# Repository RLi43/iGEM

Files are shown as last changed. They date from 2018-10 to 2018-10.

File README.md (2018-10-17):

# iGEM
iGEM 2018, Team Tsinghua-A, Hardware

http://2018.igem.org/Team:Tsinghua-A/Hardware
## Introduce
In order to achieve portable and simple field allergy detection, we designed and manufactured the hardware testing equipment for this project - a small, inexpensive ($20) system, including a device can measure OD600 and fluorescence intensity, and a small automatic vibration device avoiding the sinking of cells.

The device supports battery or micro USB for power supply. According to the prompts on the display, you can get started quickly; the device will judge your allergies based on the cell concentration and fluorescence intensity after a certain period of reaction.

In addition to the detection applied to this project, this device can also be used in other environments where fast and portable spectrophotometric detection or fluorescence intensity detection is needed.

We refer to the design of Team Aachen, 2014, but our Devices are more automated and miniaturized.
## Purchase links
* Processor - Beetle
  * http://www.dfrobot.com.cn/goods-839.html
* LED
  * https://item.taobao.com/item.htm?id=567709749083&_u=i2o6d15v87f5
* Light sensor - TSL235R
  * https://item.taobao.com/item.htm?id=565636235189&_u=i2o6d15vf405
* Filter 
  * https://item.taobao.com/item.htm?id=17750785336&_u=i2o6d15v0f55
  * https://item.taobao.com/item.htm?id=17750785336&_u=i2o6d15v0f55
* Power Module
  * https://item.taobao.com/item.htm?id=574483932087&_u=i2o6d15v1b27
* Battery
  * https://item.taobao.com/item.htm?id=572016229153&_u=i2o6d15v4163
* botton cell
  * https://detail.tmall.com/item.htm?id=546024499215&_u=i2o6d15vbf31
* botton cell holder
  * https://detail.tmall.com/item.htm?id=41299310430&_u=i2o6d15vac5e
* button
  * https://item.taobao.com/item.htm?id=555064300186&_u=i2o6d15v3976
* cuvette
  * https://item.taobao.com/item.htm?id=45424177939&_u=i2o6d15v07f3
* vibration motor
  * https://detail.tmall.com/item.htm?id=522098372457&_u=i2o6d15v0945

## Trying to make it
Following the reference on wiki, you may confort some problems. Here are some suggestions.
1. Use black material to print 3D parts. At least, paint the inside surface black. Avoiding environment light is imprtant.
2. Take care when you welding or installing parts. They are fragile.
3. Maybe you can delete some unfit design. (e.g. the fragile connection)
## Contact
About hardware : jf-li16@mails.tsinghua.edu.cn

About iGEM team Tsinghua-A 2018 : igem2018_thua@163.com

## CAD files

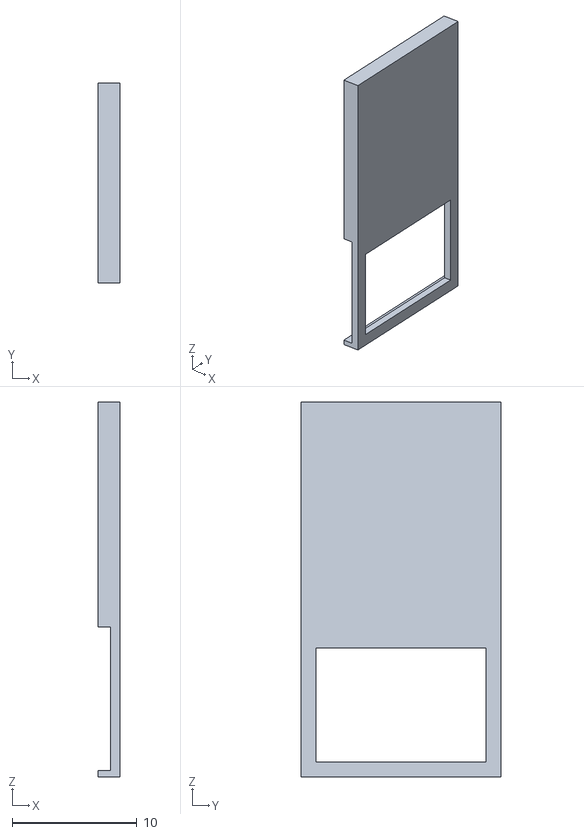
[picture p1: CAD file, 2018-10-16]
滤光片板1_v2_0.stl
1.75 x 16.0 x 30.0

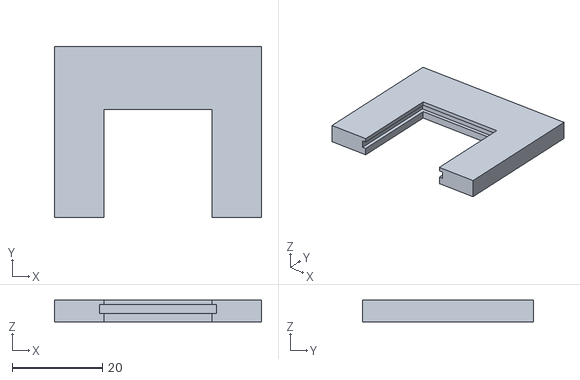
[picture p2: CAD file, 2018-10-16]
遮挡v2_1.stl
46.0 x 38.0 x 4.80

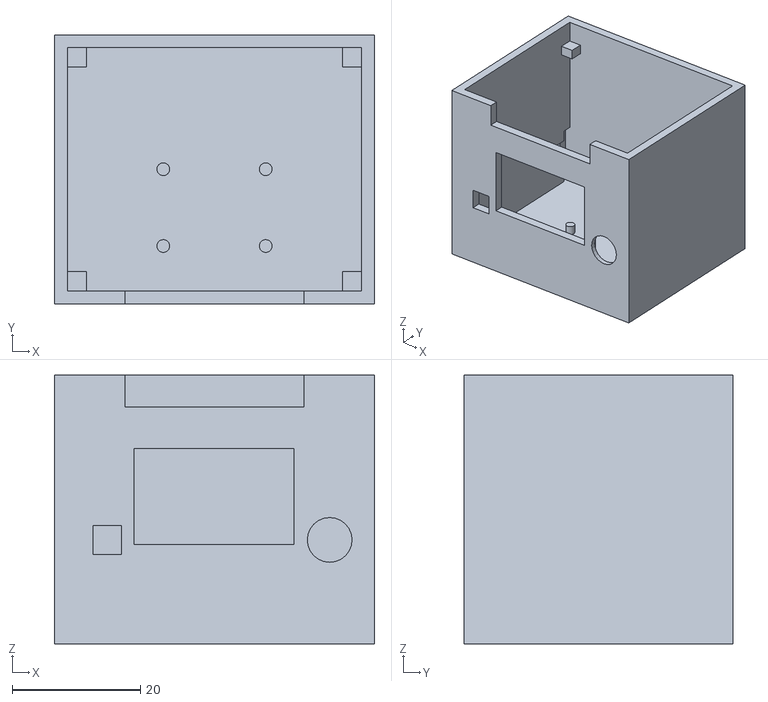
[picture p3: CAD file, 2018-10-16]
盒子外部v2_1.stl
50.0 x 42.1 x 42.0

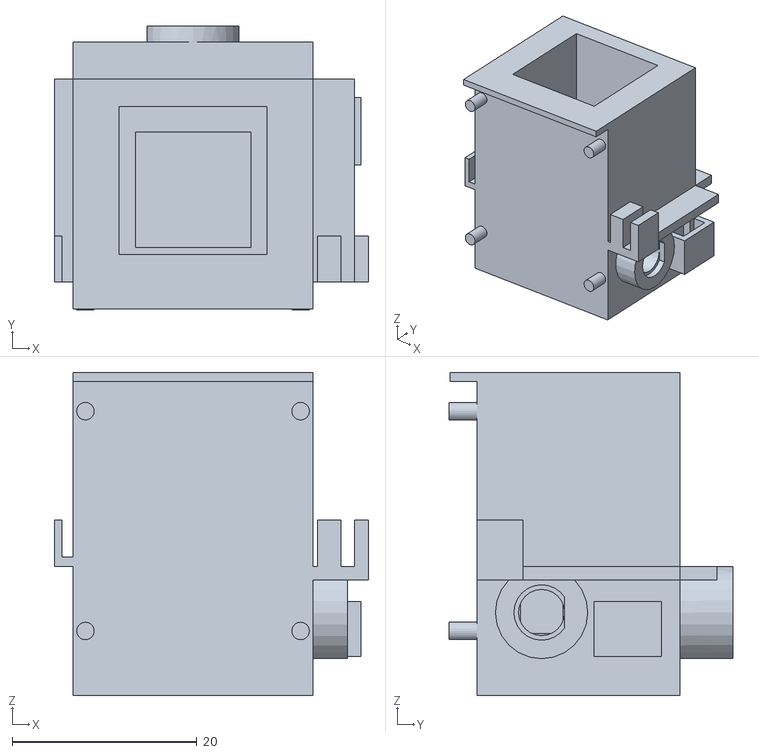
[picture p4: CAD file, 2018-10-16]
主体支架v2_0.stl
34.0 x 30.7 x 35.0

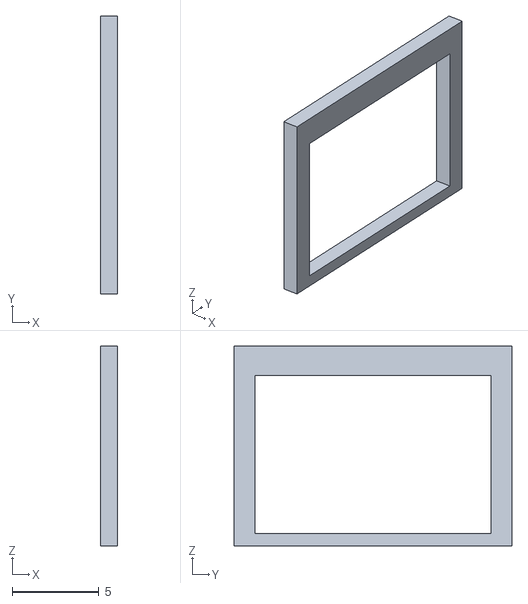
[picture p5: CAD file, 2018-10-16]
滤光片板2_v2_0.stl
1.00 x 16.0 x 11.5

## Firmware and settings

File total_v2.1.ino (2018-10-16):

/*
使用思路：
1. 活化酵母
2. 混合血浆与过敏物质，打开电源（电源键一次）
2. 等待计时结束（或者使用别的计时器，按下GO按钮跳过计时），取混合物放入比色皿中，并加入酵母溶液
3. 打开盖子，将比色皿放入孔中，按下GO按钮，等待屏幕提示
4. 屏幕提示继续时，将震荡装置贴在比色皿上，放入电池，按下GO按钮，等待反应完成
4. 待计时完成后，揭下震荡装置，然后按下GO按键//
5. 等待屏幕显示结果
6. 关闭电源，处理废品
*. 充电：左侧microUSB接口
程序思路：
1. t 计时1 过敏物质与血液的反应 GO按键跳过
2. b 空白测试 测空白的光强
3. u 计时2 组胺与酵母的反应 GO按键跳过
4. e 浓度测试 测量OD值和FL强度，并给出结果
5. w 空白等待
*/
#include <SPI.h>
#include <Wire.h>
#include <Adafruit_GFX.h>
#include <Adafruit_SSD1306.h>

//hardware
#define PIN_LED_OD A1
#define PIN_LED_FL A0
#define PIN_SEN_LIGHT_OD 0
#define PIN_SEN_LIGHT_FL 1
#define PIN_SEN_TEMP A2//Analog
#define PIN_BTN_GOON 11
#define PIN_POWER 10

//setting
#define REACTION_TIMER_1 9000 //half hour
#define REACTION_TIMER_2 1800 //half hour
#define MEASURE_TIMES 8
#define LIGHT_INTEN_OD 300
#define LIGHT_INTEN_FL 300
#define TEMP_HIGH 35
#define TEMP_LOW 20
#define THREHOLD 1

static const unsigned char PROGMEM logo[] ={  
0x00,0x00,0x00,0x00,0x00,0x00,0x00,0x00,0x00,0x00,0x00,0x00,0x00,0x00,0x00,0x00,0x00,0x00,0x00,0x00,0x00,0x00,0x00,0x00,
0x00,0x00,0x00,0x00,0x00,0x00,0x00,0x00,0x00,0x00,0x00,0x00,0x00,0x00,0x00,0x00,0x00,0x00,0x00,0x00,0x00,0x00,0x00,0x00,
0x00,0x00,0x00,0x00,0x00,0x00,0x00,0x1F,0xF0,0x00,0x00,0x00,0x00,0x00,0x00,0x00,0x00,0x00,0x00,0x00,0x00,0x00,0x01,0xFF,
0xFE,0x00,0x00,0x00,0x00,0x00,0x00,0x00,0x00,0x00,0x00,0x00,0x00,0x00,0x0F,0xFF,0xFE,0x60,0x00,0x00,0x00,0x00,0x00,0x00,
0x00,0x00,0x00,0x00,0x00,0x00,0x3F,0xFF,0xFE,0xF8,0x00,0x00,0x00,0x00,0x00,0x00,0x00,0x00,0x00,0x00,0x00,0x00,0xFF,0xFF,
0xFE,0xFE,0x00,0x00,0x00,0x00,0x00,0x00,0x00,0x00,0x00,0x00,0x00,0x01,0xFF,0xFF,0xFC,0xFF,0x00,0x00,0x00,0x00,0x00,0x00,
0x00,0x00,0x00,0x00,0x00,0x07,0xFF,0xFF,0xFC,0xFF,0x80,0x00,0x00,0x00,0x00,0x00,0x00,0x00,0x00,0x00,0x00,0x0F,0xFF,0xFF,
0xFC,0xFF,0xE0,0x00,0x00,0x00,0x00,0x00,0x00,0x00,0x00,0x00,0x00,0x1F,0xFF,0xFF,0xFC,0xFF,0xE0,0x00,0x00,0x00,0x00,0x00,
0x00,0x00,0x00,0x00,0x00,0x3F,0xFF,0xFF,0xFC,0xFF,0xE0,0x00,0x00,0x00,0x00,0x00,0x00,0x00,0x00,0x00,0x00,0x7F,0xFF,0xFF,
0xFC,0x7F,0xEC,0x00,0x00,0x00,0x00,0x00,0x00,0x00,0x00,0x00,0x00,0xFF,0xFF,0xFF,0xFB,0x3F,0xE6,0x00,0x00,0x00,0x00,0x00,
0x00,0x00,0x00,0x00,0x01,0xFD,0xFF,0xFF,0xFB,0x9F,0xF7,0x00,0x00,0x00,0x00,0x00,0x00,0x00,0x00,0x00,0x01,0xF8,0xFF,0xFF,
0xFD,0x8F,0xF7,0x00,0x00,0x00,0x00,0x00,0x00,0x00,0x00,0x00,0x03,0xF6,0x3F,0xFF,0xFC,0xC7,0xF7,0x80,0x00,0x00,0x00,0x00,
0x00,0x00,0x00,0x00,0x03,0xF3,0x9F,0xFF,0xFE,0x67,0xC7,0xC0,0x00,0x00,0x00,0x00,0x00,0x00,0x00,0x00,0x07,0xEC,0xE7,0xFF,
0xFF,0xB0,0x0F,0xC0,0x00,0x00,0x00,0x00,0x00,0x00,0x00,0x00,0x07,0xDE,0x79,0xFF,0xFF,0x98,0x3F,0xC0,0x00,0x00,0x00,0x00,
0x00,0x00,0x00,0x00,0x0F,0x9F,0x9E,0xFF,0xFF,0xD8,0x3F,0xE0,0x00,0x00,0x00,0x00,0x00,0x00,0x00,0x00,0x0F,0x3F,0xE7,0x7F,
0xFF,0xE4,0x7F,0xE0,0x00,0x00,0x00,0x00,0x00,0x00,0x00,0x00,0x0E,0x7F,0xFB,0xBF,0xFF,0xE1,0xFF,0xF0,0x00,0x00,0x00,0x00,
0x00,0x00,0x00,0x00,0x0E,0xFF,0xFD,0xFF,0xFF,0xF1,0xFF,0xF0,0x00,0x00,0x00,0x00,0x00,0x00,0x00,0x00,0x1C,0xFF,0xFE,0x3F,
0xFF,0xF9,0xFF,0xF0,0x00,0x00,0x00,0x00,0x00,0x00,0x00,0x00,0x1D,0xFF,0xFF,0x3F,0xFF,0xF9,0xFF,0xF0,0x00,0x00,0x00,0x00,
0x00,0x00,0x00,0x00,0x1C,0xFF,0xFF,0x3F,0xFF,0xFD,0xFF,0xF0,0x00,0x00,0x00,0x00,0x00,0x00,0x00,0x00,0x3E,0xFF,0xFE,0x3F,
0xFF,0xFC,0xFF,0xE0,0x00,0x00,0x00,0x00,0x00,0x00,0x00,0x00,0x3E,0x7F,0xFE,0x3F,0xFF,0xFC,0xFF,0xE0,0x00,0x00,0x00,0x00,
0x00,0x00,0x00,0x00,0x3E,0x7F,0xFE,0x1F,0xFF,0xFE,0xFF,0xE0,0x00,0x00,0x00,0x00,0x00,0x00,0x00,0x00,0x3E,0x3F,0xF0,0x1F,
0xFF,0xFE,0xFF,0xC8,0x00,0x00,0x00,0x00,0x00,0x00,0x00,0x00,0x3F,0x3F,0x86,0x1F,0xFF,0xF8,0xFF,0xC8,0x00,0x00,0x00,0x00,
0x00,0x00,0x00,0x00,0x3F,0x1C,0x0C,0x0F,0xFF,0xE3,0xFF,0x90,0x00,0x00,0x00,0x00,0x00,0x00,0x00,0x00,0x3F,0x81,0xFC,0x00,
0x3F,0xDF,0xFF,0xB0,0x00,0x00,0x00,0x00,0x00,0x00,0x00,0x00,0x3F,0xCF,0xF0,0x7F,0xBF,0xDF,0xFF,0xA0,0x00,0x00,0x00,0x00,
0x00,0x00,0x00,0x00,0x1F,0xEF,0x03,0xFF,0xBF,0xDF,0xFF,0x20,0x00,0x00,0x00,0x00,0x00,0x00,0x00,0x00,0x1F,0xE0,0x7F,0xFF,
0x7F,0xFF,0xFF,0x20,0x00,0x00,0x00,0x00,0x00,0x00,0x00,0x00,0x1F,0xFF,0xFF,0xFF,0x7F,0xA7,0xFE,0x08,0x00,0x00,0x00,0x00,
0x00,0x00,0x00,0x00,0x0F,0xFF,0xFF,0xFF,0x7F,0xB7,0xFE,0x18,0x00,0x00,0x00,0x00,0x00,0x00,0x00,0x00,0x0F,0xFF,0xFF,0xFE,
0x20,0x07,0x7C,0x10,0x00,0x00,0x00,0x00,0x00,0x00,0x00,0x00,0x0F,0xFF,0xFF,0xFF,0xE0,0xB6,0xB9,0x80,0x00,0x00,0x00,0x00,
0x00,0x00,0x00,0x00,0x0F,0xFF,0xFF,0xFF,0xFB,0xDB,0x93,0xC0,0x00,0x00,0x00,0x00,0x00,0x00,0x00,0x00,0x07,0xFF,0xFF,0xFF,
0xF3,0xFB,0xC7,0xE0,0x00,0x00,0x00,0x00,0x00,0x00,0x00,0x00,0x07,0xFF,0xFF,0xFF,0xF7,0xFB,0xCF,0xC0,0x00,0x00,0x00,0x00,
0x00,0x00,0x00,0x00,0x03,0xFF,0xFF,0xFF,0xE7,0x99,0xFF,0xC0,0x00,0x00,0x00,0x00,0x00,0x00,0x00,0x00,0x03,0xFF,0xFF,0xFF,
0xFF,0x99,0xFF,0x80,0x00,0x00,0x00,0x00,0x00,0x00,0x00,0x00,0x01,0xFF,0xFF,0xFF,0xE6,0x1D,0xFF,0x80,0x00,0x00,0x00,0x00,
0x00,0x00,0x00,0x00,0x01,0xFF,0xFF,0xE7,0xE6,0x1C,0xFF,0x00,0x00,0x00,0x00,0x00,0x00,0x00,0x00,0x00,0x00,0xFF,0xFF,0xC1,
0xCB,0xC8,0xFF,0x00,0x00,0x00,0x00,0x00,0x00,0x00,0x00,0x00,0x00,0x7F,0xFF,0x3C,0x41,0xE1,0xFE,0x00,0x00,0x00,0x00,0x00,
0x00,0x00,0x00,0x00,0x00,0x01,0xFE,0x7F,0x9E,0xF3,0xFC,0x00,0x00,0x00,0x00,0x00,0x00,0x00,0x00,0x00,0x00,0x18,0x5C,0x7F,
0xFF,0xCF,0xF8,0x00,0x00,0x00,0x00,0x00,0x00,0x00,0x00,0x00,0x00,0x0E,0x00,0xFF,0xFF,0xBF,0xF0,0x00,0x00,0x00,0x00,0x00,
0x00,0x00,0x00,0x00,0x00,0x07,0x80,0xFF,0xFF,0x7F,0xE0,0x00,0x00,0x00,0x00,0x00,0x00,0x00,0x00,0x00,0x00,0x03,0xC0,0xFF,
0xFE,0xFF,0x80,0x00,0x00,0x00,0x00,0x00,0x00,0x00,0x00,0x00,0x00,0x01,0xCD,0xFF,0xFE,0x3F,0x00,0x00,0x00,0x00,0x00,0x00,
0x00,0x00,0x00,0x00,0x00,0x00,0x4D,0xFF,0xFF,0x9E,0x00,0x00,0x00,0x00,0x00,0x00,0x00,0x00,0x00,0x00,0x00,0x00,0x1D,0xFF,
0xFF,0xC0,0x00,0x00,0x00,0x00,0x00,0x00,0x00,0x00,0x00,0x00,0x00,0x00,0x09,0xFF,0xFF,0xE0,0x00,0x00,0x00,0x00,0x00,0x00,
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

#define OLED_RESET 4
Adafruit_SSD1306 display(OLED_RESET);

#define ACTIVE_GAP 15000
unsigned long oldMillis = 0; 

bool btn_old_stat = false;
char state = 'i';

float getTemp(int anv=8) // defaut sample times is 8
{
  int sum = 0;
  for(int i = 0; i < anv; i++){
    sum+=analogRead(PIN_SEN_TEMP);
    delay(100);// this can change
  }
  return sum*500.0/anv/1024;
}

volatile unsigned long cnt = 0;
void interrupt(){
  cnt++;
}

unsigned long blank_fl = 0;
unsigned long blank_od = 0;
unsigned long black_fl = 0;
unsigned long black_od = 0;
bool Allergen ;

unsigned long oldMicros = 0;
unsigned long _getLightIntenFreq(int Pin)//Led_pin
//100ms - 10Hz
{
  int num = PIN_SEN_LIGHT_OD ;
  if(Pin == PIN_LED_FL)num = PIN_SEN_LIGHT_FL;
  attachInterrupt(num+2,interrupt,CHANGE);//twice
  oldMicros = micros();
  cnt = 0;
  while(micros()-oldMicros<100000){}
  unsigned long detect_cnt = cnt;
  return detect_cnt;
}
unsigned long getLightIntenFreq(int int_Pin,int Inten){
  analogWrite(int_Pin,Inten);
  delay(10);
  unsigned long sum = 0;
  for(int i = 0; i < MEASURE_TIMES; i++){
    sum += _getLightIntenFreq(int_Pin);
  }
  digitalWrite(int_Pin,LOW);
  return sum / MEASURE_TIMES;
}

bool goon(){
  bool now_stat = digitalRead(PIN_BTN_GOON);
  if(now_stat!=btn_old_stat){
    btn_old_stat = now_stat;
    return true;
  }
  return false;
}

unsigned int timer_cnt = 0;
unsigned long timer_oldMilis = 0;
void time_display(unsigned int seconds){
  unsigned short min = seconds/60;
  unsigned short sec = seconds-min*60;  
    display.clearDisplay();
    display.setTextSize(3);
    display.setCursor(10,10); 
    display.print(min);                
    display.print(":");
    display.print(sec);   
    display.display();   
}

void setup(){
  pinMode(PIN_LED_FL,OUTPUT);
  pinMode(PIN_LED_OD,OUTPUT);
  pinMode(PIN_SEN_TEMP,INPUT);
  pinMode(PIN_SEN_LIGHT_FL,INPUT);
  pinMode(PIN_SEN_LIGHT_OD,INPUT);
  pinMode(PIN_BTN_GOON,INPUT_PULLUP);
  pinMode(PIN_POWER,OUTPUT);
  digitalWrite(PIN_LED_FL,LOW);
  digitalWrite(PIN_LED_OD,LOW);
  digitalWrite(PIN_POWER,HIGH);
  oldMillis = millis();
  
  //Serial.begin(9600);
  display.begin(SSD1306_SWITCHCAPVCC, 0x3C);  // initialize with the I2C addr 0x3D (for the 128x64) 
  btn_old_stat = digitalRead(PIN_BTN_GOON);
  state = 'i';

  //show logo
  display.clearDisplay();
  display.drawBitmap(0, 0, logo, 128, 64, 1); 
  display.display();
  delay(2000);

  display.clearDisplay();
  display.setCursor(0,4); 
  display.setTextSize(2);             //设置字体大小
  display.setTextColor(WHITE);        //设置字体白色
  display.println("Tsinghua-A");                //输出字符
  display.print("Welcome!");                //输出字符
  display.display();
  delay(2000);
}

void loop(){
  switch (state){
    case 'i':{//initial      
      float tp = getTemp();
      display.clearDisplay();
      display.setTextSize(2);
      display.setCursor(0,0);
      display.println("Temp: 28-30C is the best");
      display.print(tp);
      display.display();
      delay(1000);
      if(tp > TEMP_HIGH || tp < TEMP_LOW){
        display.clearDisplay();
        display.setCursor(0,0);
        display.println("Temp not fit.28-30C is the best");
        display.display();
        delay(2000);
      }else{
        if(goon()){
          state = 't';
          timer_cnt = REACTION_TIMER_1;
          timer_oldMilis = millis();
          time_display(timer_cnt);
          delay(400);
          black_fl = _getLightIntenFreq(PIN_LED_FL);
          black_od = _getLightIntenFreq(PIN_LED_OD);
          break;
        }
        display.clearDisplay();
        display.setCursor(0,0);
        display.println("Mix blood & allergen. Close Box.Then GO");
        display.display();
        delay(1000);
      }
      break;}
    case 't':{//timing
      if(timer_cnt == 0 || goon()){
        state = 'b';
        break;
      }
      unsigned long now_mili = millis();
      if(now_mili-timer_oldMilis>1000){
        timer_cnt -= (now_mili-timer_oldMilis)/1000;
        timer_oldMilis = now_mili;
        time_display(timer_cnt);
      }
      delay(400);
      break;}
    case 'b'://blank
      display.setTextSize(2);
      display.clearDisplay();
      display.setTextSize(2);
      display.setCursor(0,0);
      display.println("Add mixture and yeast to cuvette.");
      display.display();
      delay(2000);
      display.clearDisplay();
      display.setCursor(0,0);
      display.println("Put cuvette in the hole Then GO");
      display.display();
      delay(2000);
      if(goon()){
        state = 'm';

        blank_fl = getLightIntenFreq(PIN_LED_FL,LIGHT_INTEN_FL);
        blank_od = getLightIntenFreq(PIN_LED_OD,LIGHT_INTEN_OD);

      }
      break;
    case 'm':{
      display.clearDisplay();
      display.setCursor(0,0);
      display.println("stick the oscillomotor to cuvette.GO");
      display.display();
      delay(2000);
      if(goon()){
        state = 'u';
        timer_cnt = REACTION_TIMER_2;
        timer_oldMilis = millis();
        time_display(timer_cnt);
        delay(400);
      }
      break;
    }
    case 'u':{//timing2
      if(timer_cnt == 0 || goon()){
        state = 'o';
        break;
      }
      unsigned long now_mili = millis();
      if(now_mili-timer_oldMilis>1000){
        timer_cnt -= (now_mili-timer_oldMilis)/1000;
        timer_oldMilis = now_mili;
        time_display(timer_cnt);
        delay(400);
      }
      break;}
    case 'o':{
      display.setTextSize(2);
      if(goon()){state = 'e';break;}

      display.clearDisplay();
      display.setCursor(0,0);
      display.println("dettach oscillomotor from cuvette.");
      display.display();
      delay(2000);
      display.clearDisplay();
      display.setCursor(0,0);
      display.println("Close the box. GO!");
      display.display();
      delay(2000);
      break;
    }
    case 'e': {  
      display.setTextSize(3);
      //measure OD600
      double value_OD = log10((getLightIntenFreq(PIN_LED_OD,LIGHT_INTEN_OD) - black_od)/(blank_od - black_od));
      //measure Flourence
      double value_FL = log10( (getLightIntenFreq(PIN_LED_FL,LIGHT_INTEN_FL) - black_fl)/(blank_fl - black_fl));

      //calculate&diplay
      //allergy
      if(value_FL/value_OD > THREHOLD){
        Allergen = true;
        display.clearDisplay();
        display.setCursor(0,0);
        display.println("An");
        display.println("allergy");
        display.display();
      }else{
        Allergen = false;
        display.clearDisplay();
        display.setCursor(0,0);
        display.println("Not");
        display.println("allergy");
        display.display();
      }
        state = 'n';
      break;}
    case 'n':
      display.clearDisplay();
      display.setCursor(0,0);      
      if(Allergen) display.println("An");
      else display.println("Not");
      display.println("allergy");
      display.display();
      if(goon()) state = 'd';
      break;
    case 'd':
      //显示已完成
        display.clearDisplay();
        display.drawBitmap(0, 0, logo, 128, 64, 1); 
        display.display();
        if(goon()) state = 'i';
        delay(1000);
      break;
  }

  if( millis() - oldMillis > ACTIVE_GAP){
    digitalWrite(PIN_POWER,LOW);
    delay(100);
    digitalWrite(PIN_POWER,HIGH);
    oldMillis = millis();
  }
}

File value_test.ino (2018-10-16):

//show light intensity

#include <SPI.h>
#include <Wire.h>
#include <Adafruit_GFX.h>
#include <Adafruit_SSD1306.h>
#define OLED_RESET 4
Adafruit_SSD1306 display(OLED_RESET);

//hardware
#define PIN_LED_OD A1
#define PIN_LED_FL A0
#define PIN_SEN_LIGHT_OD 0
#define PIN_SEN_LIGHT_FL 1
#define PIN_SEN_TEMP A2//Analog
#define PIN_BTN_GOON 11

#define REACTION_TIMER 1800 //half hour
#define MEASURE_TIMES 8

unsigned int timer_cnt = 0;
unsigned long timer_oldMilis = 0;
void time_display(unsigned int seconds){
    unsigned short mins = seconds/60;
    unsigned short sec = seconds-mins*60;  
    display.clearDisplay();
    display.setTextSize(3);
    display.setCursor(10,10); 
    display.print(mins);                
    display.print(":");
    display.print(sec);   
    display.display();   
}

bool btn_old_stat = false;
bool goon(){
  bool now_stat = digitalRead(PIN_BTN_GOON);
  if(now_stat!=btn_old_stat){
    btn_old_stat = now_stat;
    return true;
  }
  return false;
}

unsigned long oldMilis = 0;
volatile unsigned long cnt = 0;
void interrupt()
{
  cnt++;
}

unsigned long _getLightIntenFreq(int Pin)
//num 0 for a sensor, 1 for another
//1000ms - 1Hz
{
  int num = PIN_SEN_LIGHT_OD ;
  if(Pin == PIN_LED_FL)num = PIN_SEN_LIGHT_FL;
  attachInterrupt(num+2,interrupt,RISING);
  delay(100);
  oldMilis = micros();
  cnt = 0;
  while(micros()-oldMilis<100000){}
  unsigned long detect_cnt = cnt;
  return detect_cnt;// it needs to be calculate
}
unsigned long getLightIntenFreq(int int_Pin,int Inten){
  analogWrite(int_Pin,Inten);
  delay(10);//actually, there may be no need of this delay
  unsigned long sum = 0;
  for(int i = 0; i < MEASURE_TIMES; i++){
    sum += _getLightIntenFreq(int_Pin);
  }
  //unsigned long lightInten=getLightIntenFreq(int_Pin);
  digitalWrite(int_Pin,LOW);
  return sum / MEASURE_TIMES;
}
float getTemp(int anv=8) // defaut sample times is 8
{
  float sum = 0;
  for(int i = 0; i < anv; i++){
    sum+=analogRead(PIN_SEN_TEMP);
    delay(100);// this can change
  }
  return sum*500.0/anv/1024;
}

void setup(){
  pinMode(PIN_LED_FL,OUTPUT);
  pinMode(PIN_LED_OD,OUTPUT);
  pinMode(PIN_SEN_TEMP,INPUT);
  pinMode(PIN_SEN_LIGHT_FL,INPUT);
  pinMode(PIN_SEN_LIGHT_OD,INPUT);
  pinMode(PIN_BTN_GOON,INPUT_PULLUP);

  Serial.begin(9600);

  display.begin(SSD1306_SWITCHCAPVCC, 0x3C);  // initialize with the I2C addr 0x3D (for the 128x64)  
  //show logo

    display.clearDisplay();
    display.setCursor(0,10); 
    display.setTextSize(2);             //设置字体大小
    display.setTextColor(WHITE);        //设置字体白色
    display.println("Tsinghua-A");                //输出字符
    display.println("Welcome!");                //输出字符
    display.display();
    delay(2000);

  btn_old_stat = digitalRead(PIN_BTN_GOON);
  timer_cnt = REACTION_TIMER;
  timer_oldMilis = millis();
}
int state = 0;
void loop(){
    if(goon())state++;
    state = state % 4;
    display.setTextSize(2);    
    display.clearDisplay();
    switch (state)
    {
        case 0:{
            display.setCursor(0,10); 
            display.println("OD:");
            unsigned long od = getLightIntenFreq(PIN_LED_OD,300);
            Serial.println(od);
            display.println(od);                //输出字符            
            break;}
        case 1:{
            display.setCursor(0,10); 
            display.println("FL:");
            display.setCursor(0,30); 
            unsigned long fl = getLightIntenFreq(PIN_LED_FL,800);
            Serial.println(fl);
            display.println(fl);                //输出字符            
            break;}
        case 2:{
            display.setCursor(0,10);
            display.println("Black");            
            unsigned long bl = _getLightIntenFreq(PIN_LED_OD);
            display.print(bl);
            display.print("-");
            delay(1000);
            bl = _getLightIntenFreq(PIN_LED_FL);
            display.println(bl);
            break;}
        case 3:{
            display.setCursor(0,10); 
            display.print("TP:  ");
            display.println(getTemp());                //输出字符            
            delay(2000);
            display.setCursor(0,10); 
            display.println("Time:");
            if(timer_cnt == 0)timer_cnt == REACTION_TIMER;
            unsigned long now_mili = millis();
            timer_cnt-=(now_mili - timer_oldMilis)/1000;
            time_display(timer_cnt);
            if(now_mili - timer_oldMilis > 1000){
                timer_oldMilis = now_mili;
            }
            break;}
        default:
            break;
    }
    display.display();
    delay(1000);
    display.invertDisplay(true);
    delay(200);
    display.invertDisplay(false);
}
